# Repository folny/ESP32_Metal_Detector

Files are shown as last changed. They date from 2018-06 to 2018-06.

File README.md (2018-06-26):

# ESP32 Metal Detector

BLE Library https://github.com/nkolban/ESP32_BLE_Arduino

Forum http://www.geotech1.com/forums/showthread.php?24589-ESP32-Metal-detector

https://www.youtube.com/watch?v=ikg0VJCtUzE

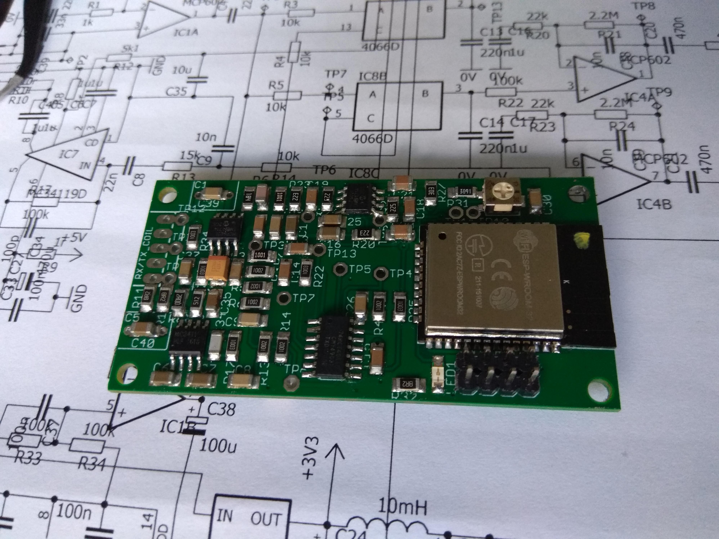
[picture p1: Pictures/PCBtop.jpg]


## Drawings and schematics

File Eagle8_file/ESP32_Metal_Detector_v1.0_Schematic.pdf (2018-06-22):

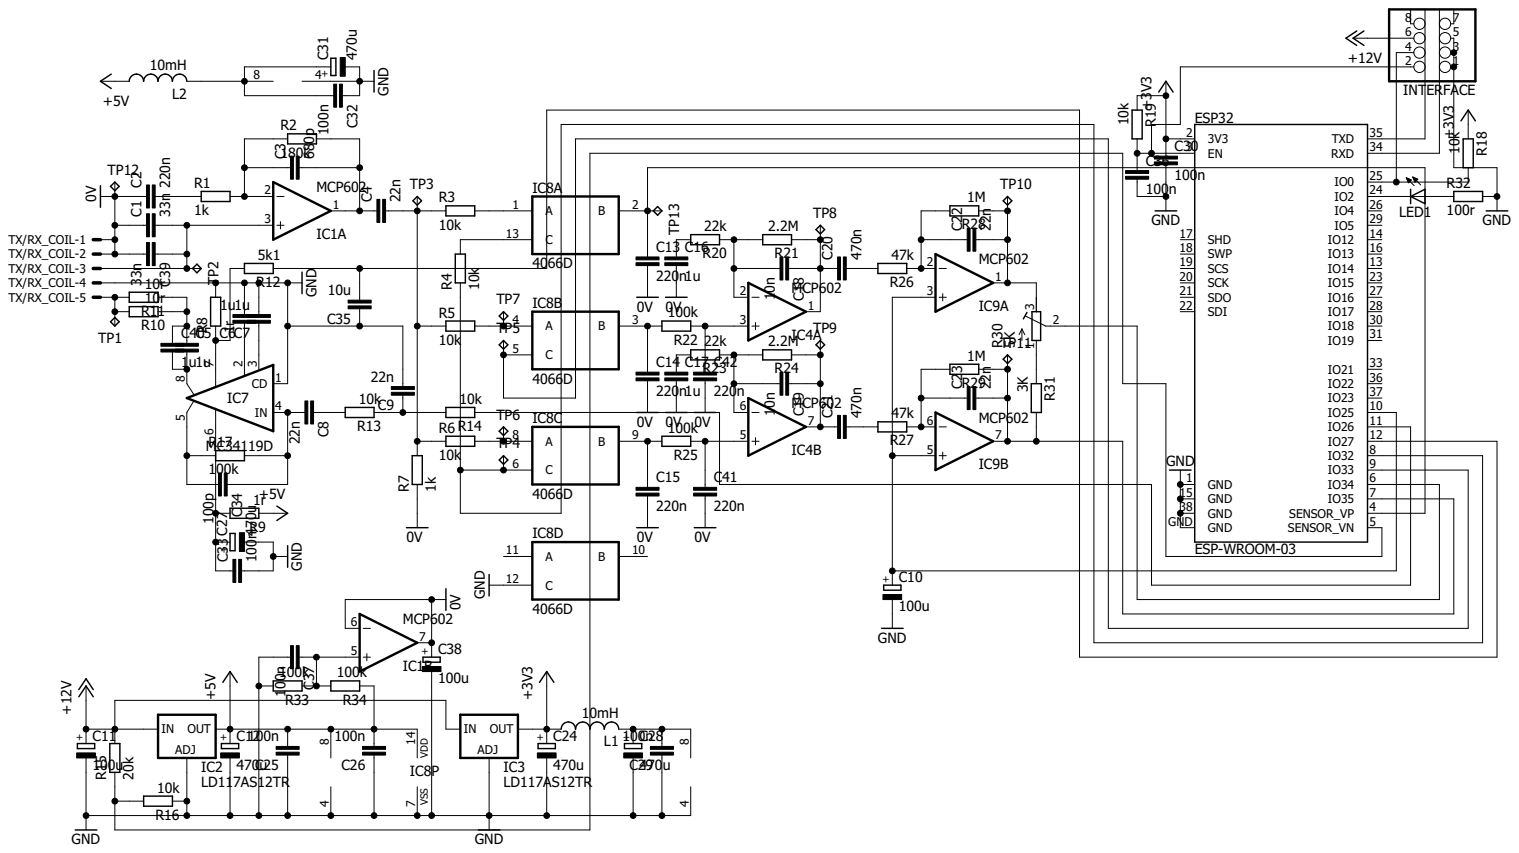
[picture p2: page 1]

TX/RX_COIL-1 TX/RX_COIL-2 TX/RX_COIL-3 TX/RX_COIL-4 TX/RX_COIL-5

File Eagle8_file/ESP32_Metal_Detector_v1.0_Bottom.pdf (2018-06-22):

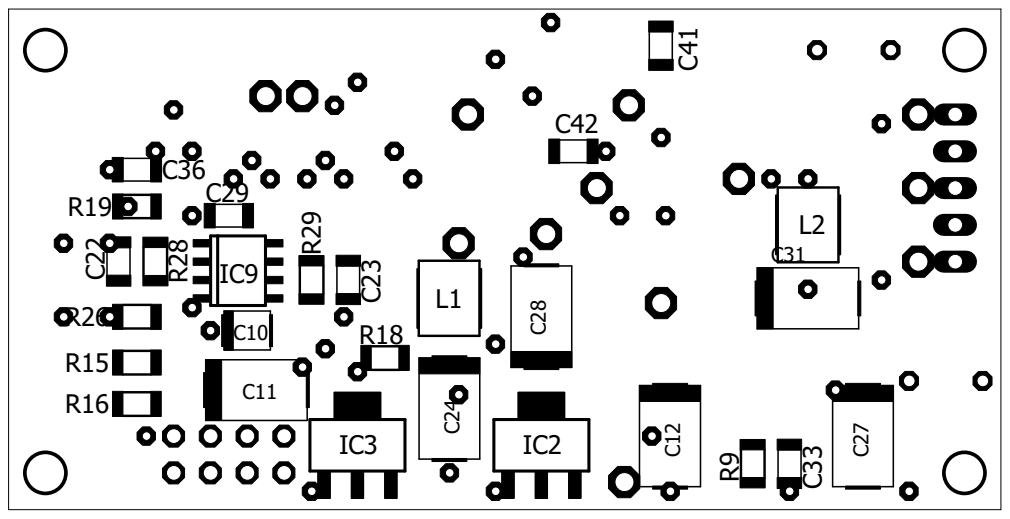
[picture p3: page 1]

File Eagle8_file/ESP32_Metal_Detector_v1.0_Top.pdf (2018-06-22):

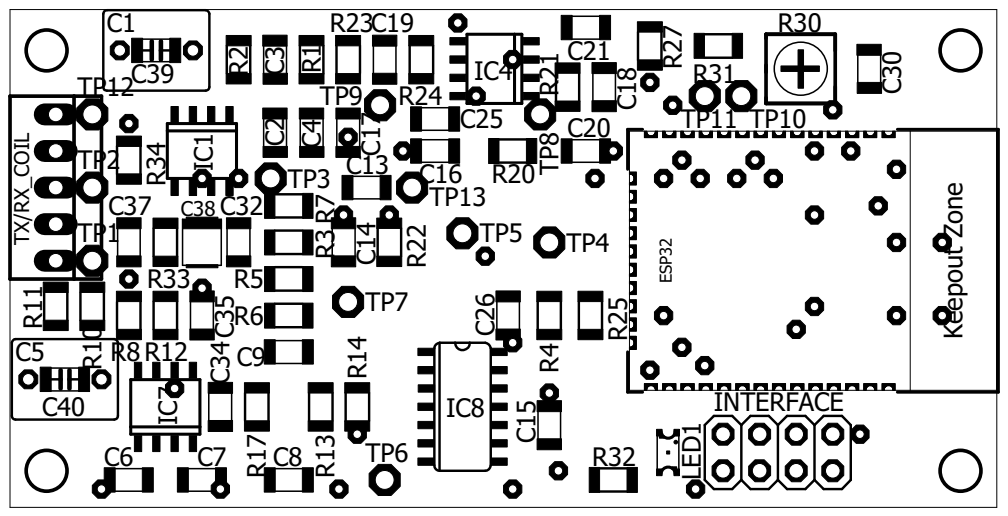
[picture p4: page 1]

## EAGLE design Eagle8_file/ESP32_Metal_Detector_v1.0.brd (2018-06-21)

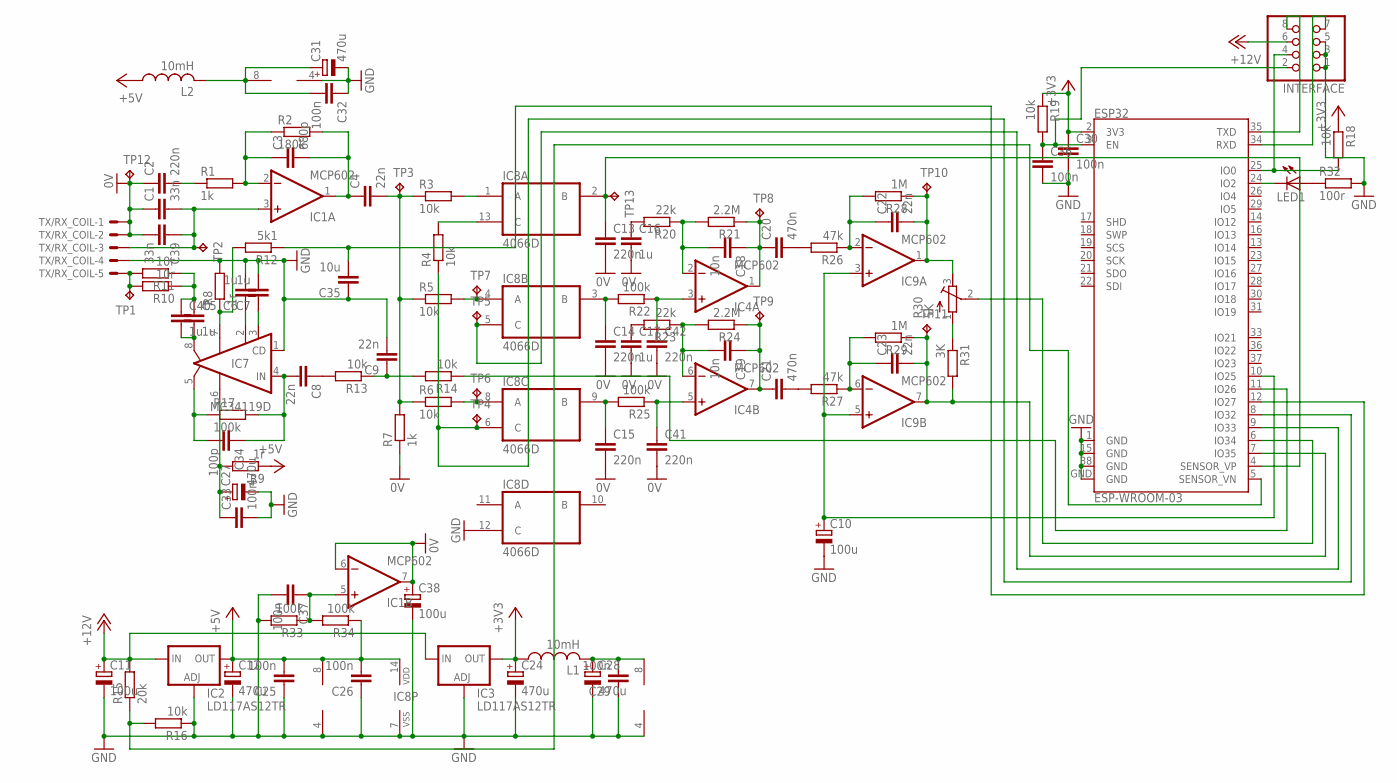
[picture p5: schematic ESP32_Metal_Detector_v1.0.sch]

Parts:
C1: 33n; C050-055X075
C2, C13, C14, C15, C41, C42: 220n; C1206
C3: 680p; C1206
C4, C8, C9, C22, C23: 22n; C1206
C5: 1u; C050-055X075
C6, C7, C16, C17, C40: 1u; C1206
C10, C38: 100u; SMC_B
C11: 100u; SMC_E
C12, C24, C27, C28, C31: 470u; SMC_D
C18, C19: 10n; C1206
C20, C21: 470n; C1206
C25, C26, C29, C30, C32, C33, C36, C37: 100n; C1206
C34: 100p; C1206
C35: 10u; C1206
C39: 33n; C1206
ESP32: ESP-WROOM-03
IC1, IC4, IC9: MCP602; SO08
IC2, IC3: LD117AS12TR; SOT223
IC7: MC34119D; SO08
IC8: 4066D; SO14
INTERFACE: PINHD-2X4; 2X04
L1, L2: 10mH; L5650M
LED1: LEDSML1206; SML1206
R1, R7: 1k; R1206
R2: 180k; R1206
R3, R4, R5, R6, R13, R14, R16, R18, R19: 10k; R1206
R8, R9: 1r; R1206
R10, R11: 10r; R1206
R12: 5k1; R1206
R15: 20k; R1206
R17, R22, R25, R33, R34: 100k; R1206
R20, R23: 22k; R1206
R21, R24: 2.2M; R1206
R26, R27: 47k; R1206
R28, R29: 1M; R1206
R30: 5K; RTRIM4G/J
R31: 3K; R1206
R32: 100r; R1206
TP1, TP2, TP3, TP4, TP5, TP6, TP7, TP8, TP9, TP10, TP11, TP12, TP13: TPPAD1-13; P1-13
TX/RX_COIL: 22-23-2051

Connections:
0V: C1.1, C2.1, C13.2, C14.2, C15.2, C16.2, C17.2, C38.+, C39.2, C41.2, C42.2, IC1.6 (-IN), IC1.7 (OUT), R7.1, TP12.TP, TX/RX_COIL.1, TX/RX_COIL.2
+3V3: C24.+, C30.1, ESP32.2 (3V3), IC3.4 (OUT), L1.1, R18.1, R19.1
+5V: C12.+, C25.2, C26.2, IC2.4 (OUT), IC4.8 (V+), IC8.14 (VDD), L2.1, R9.1, R34.1
+12V: C11.+, IC2.3 (IN), IC3.3 (IN), INTERFACE.6, R15.2
GND: C6.2, C7.2, C9.2, C10.-, C11.-, C12.-, C24.-, C25.1, C26.1, C27.-, C28.-, C29.1, C30.2, C31.-, C32.1, C33.2, C35.1, C36.2, C37.2, C38.-, ESP32.1 (GND), ESP32.15 (GND), ESP32.38 (GND), ESP32.GND, IC1.4 (V-), IC2.1 (ADJ), IC3.1 (ADJ), IC4.4 (V-), IC7.1 (CD), IC8.7 (VSS), IC8.12 (C), IC9.4 (V-), INTERFACE.1, INTERFACE.3, INTERFACE.5, R8.2, R16.1, R32.2, R33.2, TX/RX_COIL.4
unnamed: C3.2, C4.1, IC1.1 (OUT), R2.2
unnamed: R30.1 (A), R31.1
unnamed: C1.2, C39.1, IC1.3 (+IN), TP2.TP, TX/RX_COIL.3
unnamed: C2.2, R1.1
unnamed: C3.1, IC1.2 (-IN), R1.2, R2.1
unnamed: ESP32.8 (IO32), IC8.6 (C), R4.1, TP4.TP
unnamed: IC8.1 (A), R3.2
unnamed: IC8.8 (A), R6.2, TP6.TP
unnamed: C4.2, R3.1, R5.1, R6.1, R7.2, TP3.TP
unnamed: C22.2, IC9.1 (OUT), R28.1, R30.3 (E), TP10.TP
unnamed: IC8.13 (C), R4.2
unnamed: C5.2, C40.2, IC7.8 (VO2)
unnamed: C5.1, C40.1, R10.1, R11.1
unnamed: C15.1, IC8.9 (B), R25.2
unnamed: C27.+, C33.1, IC7.6 (VCC), R9.2
unnamed: IC7.7 (GND), R8.1, R12.2
unnamed: C6.1, IC7.2 (FC2)
unnamed: C7.1, IC7.3 (FC1)
unnamed: C8.2, C34.1, IC7.4 (IN), R17.2
unnamed: C8.1, R13.2
unnamed: C9.1, R13.1, R14.2
unnamed: ESP32.11 (IO26), R14.1
unnamed: C28.+, C29.2, IC9.8 (V+), L1.2
unnamed: IC8.4 (A), R5.2, TP7.TP
unnamed: C14.1, IC8.3 (B), R22.2
unnamed: ESP32.5 (SENSOR_VN), R15.1, R16.2
unnamed: ESP32.9 (IO33), IC8.5 (C), TP5.TP
unnamed: ESP32.6 (IO34), R30.2 (S)
unnamed: C13.1, ESP32.4 (SENSOR_VP), IC8.2 (B), TP13.TP
unnamed: C31.+, C32.2, IC1.8 (V+), L2.2
unnamed: C34.2, IC7.5 (VO1), R17.1
unnamed: C18.1, C20.1, IC4.1 (OUT), R21.1, TP8.TP
unnamed: C18.2, IC4.2 (-IN), R20.1, R21.2
unnamed: C19.2, IC4.6 (-IN), R23.1, R24.2
unnamed: C35.2, ESP32.12 (IO27), R12.1
unnamed: C42.1, IC4.3 (+IN), R22.1
unnamed: C41.1, IC4.5 (+IN), R25.1
unnamed: C20.2, R26.2
unnamed: C21.2, R27.2
unnamed: C23.1, IC9.6 (-IN), R27.1, R29.2
unnamed: C22.1, IC9.2 (-IN), R26.1, R28.2
unnamed: ESP32.25 (IO0), INTERFACE.4, R18.2
unnamed: C23.2, ESP32.7 (IO35), IC9.7 (OUT), R29.1, R31.2, TP11.TP
unnamed: C10.+, ESP32.10 (IO25), IC9.3 (+IN), IC9.5 (+IN)
unnamed: C19.1, C21.1, IC4.7 (OUT), R24.1, TP9.TP
unnamed: LED1.A, R32.1
unnamed: C36.1, ESP32.3 (EN), INTERFACE.2, R19.2
unnamed: C16.1, R20.2
unnamed: C17.1, R23.2
unnamed: R10.2, R11.2, TP1.TP, TX/RX_COIL.5
unnamed: ESP32.24 (IO2), LED1.C
unnamed: C37.1, IC1.5 (+IN), R33.1, R34.2
unnamed: ESP32.35 (TXD), INTERFACE.8
unnamed: ESP32.34 (RXD), INTERFACE.7

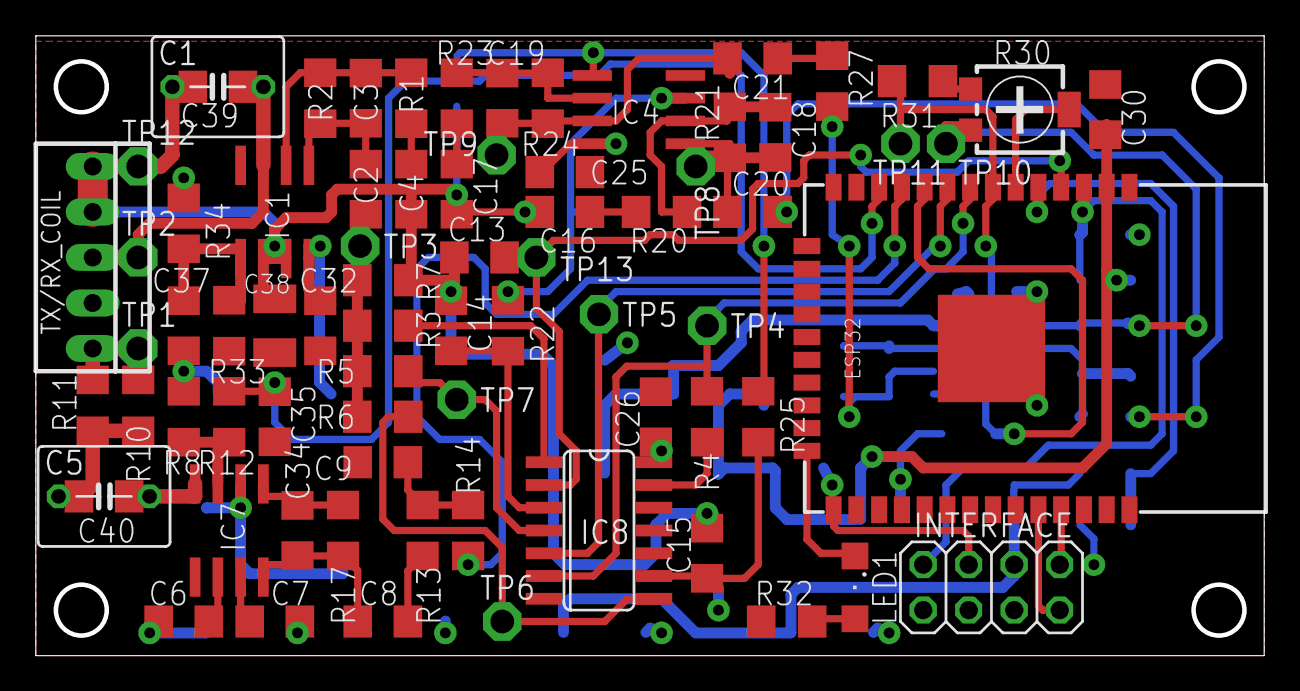
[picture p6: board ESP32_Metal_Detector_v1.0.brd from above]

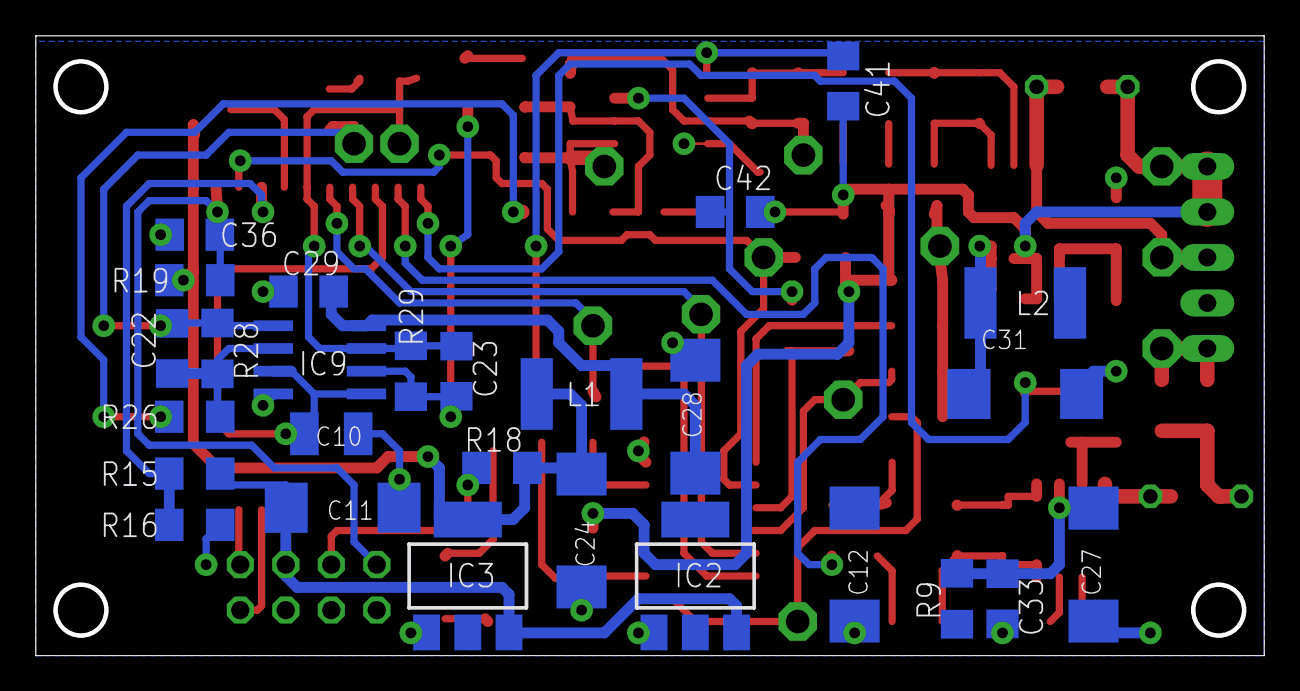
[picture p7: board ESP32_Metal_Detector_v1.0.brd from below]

Board: 2 copper layers, 68.6 x 34.6 mm, 102 parts (27 on the bottom side), 59 nets.

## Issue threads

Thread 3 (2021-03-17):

setup process step by step

DVB-Arduino, 2021-03-17:
I made this project. But I can't configure it. The firmware is uploaded to ESP32, the phone sees the bluetooth of the metal detector and connects ..
But I ran into a problem:
1. APK application does not work on Android 10. Writes that the program was created for an early version of Android.
2. No generation on IO26 ESP32. (transmitting signal)

Can you describe the setup process step by step?

renat2985, 2021-04-06:
Can you show how you connected the board to the coil?

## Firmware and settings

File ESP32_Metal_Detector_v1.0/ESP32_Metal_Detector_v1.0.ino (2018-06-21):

#include <WiFi.h>
#include <ESPmDNS.h>
#include <WiFiUdp.h>
#include <ArduinoOTA.h>
#include <EEPROM.h>
#include <Arduino.h>
#include <driver/dac.h>
#include <BLEDevice.h>
#include <BLEServer.h>
#include <BLEUtils.h>
#include <BLE2902.h>

#include "defs.h"
#include "params.h"
#include "config.h"

bool InfoSend = 0;
bool ledStatus = 0;
bool CalibZeroSelected = 0;
bool CalibMaxSelected = 0;

CParameters params;
extern CParameters params;

const char* ssid = "ESP32 Metal Detector";
const char* password = "detectorupdate";

int VDI = 0;
int MSG = 0;

char DataString[16];

BLECharacteristic *pCharacteristic_RX;
BLECharacteristic *pCharacteristic_TX;

bool deviceConnected = false;

#define SERVICE_UUID                 "6E400001-B5A3-F393-E0A9-E50E24DCCA9E"
#define CHARACTERISTIC_UUID_RX       "6E400002-B5A3-F393-E0A9-E50E24DCCA9E"
#define CHARACTERISTIC_UUID_TX       "6E400003-B5A3-F393-E0A9-E50E24DCCA9E"

class MyServerCallbacks: public BLEServerCallbacks {
    void onConnect(BLEServer* pServer) {
      deviceConnected = true;
      ledStatus = 0;
      InfoSend = 1;
      digitalWrite(2, HIGH);
      Serial.println("Bluetooth Connected");
    };

void onDisconnect(BLEServer* pServer) {
      deviceConnected = false;
      ledStatus = 1;
      Serial.println("Bluetooth Disonnected");
      //ESP.restart();
    }
};

class MyCallbacks: public BLECharacteristicCallbacks {
    void onWrite(BLECharacteristic *pCharacteristic) {
      std::string rxValue = pCharacteristic->getValue();

//////////////////////////////////////////////////////////////////

if (rxValue.find("B") != -1)
        { 
     if (params.m_minSignal <255)
        {
         params.m_minSignal ++;//if pin0 is pressed and the duty ratio value is less than 255
         delay(50);                                               
        }
        }
     if (rxValue.find("A") != -1)
        {
     if (params.m_minSignal >0)
        {
         params.m_minSignal --;// if pin1 is pressed and the duty ratio value is greater than 0
         delay(50);                                              
        }                                                
}
        
//////////////////////////////////////////////////////////////////

if (rxValue.find("D") != -1)
        { 
     if (params.m_readingSamples <255)
        {
         params.m_readingSamples ++;//if pin0 is pressed and the duty ratio value is less than 255
         delay(50);                                               
        }
        }
     if (rxValue.find("C") != -1)
        {
     if (params.m_readingSamples >0)
        {
         params.m_readingSamples --;// if pin1 is pressed and the duty ratio value is greater than 0
         delay(50);                                              
        }                                                
}
         
//////////////////////////////////////////////////////////////////

if (rxValue.find("F") != -1)
        { 
     if (params.m_Phase_X <255)
        {
         params.m_Phase_X ++;//if pin0 is pressed and the duty ratio value is less than 255
         delay(50);                                               
        }
        }
     if (rxValue.find("E") != -1)
        {
     if (params.m_Phase_X >0)
        {
         params.m_Phase_X --;// if pin1 is pressed and the duty ratio value is greater than 0
         delay(50);                                              
        }                                                
}
         
//////////////////////////////////////////////////////////////////

         if (rxValue.find("I") != -1) {
         CalibZeroSelected = 1;      
       }
       
         if (rxValue.find("J") != -1) {
         CalibMaxSelected = 1;
       }
             
         EEPROMWriteInt(2, params.m_minSignal);
         EEPROMWriteInt(10, params.m_readingSamples);
         EEPROMWriteInt(14, params.m_Phase_X);
         Serial.print("MinSignal EEPROM Write :"); 
         Serial.println(params.m_minSignal);
         Serial.print("ReadingSamples EEPROM Write :"); 
         Serial.println(params.m_readingSamples);
         Serial.print("Phase_X EEPROM Write :"); 
         Serial.println(params.m_Phase_X);
    }
};

///////////////////////////////////////////////////////////////////////////////////////////////////////
//signal processing
bool generateReading(int* pPhase, int* pStrength, unsigned char* signalValues, bool* pbadReading) 
{
    #define SAMPLE_BUFFER_SIZE 350
    unsigned char strenth[SAMPLE_BUFFER_SIZE] = {0,};
    unsigned char angle[SAMPLE_BUFFER_SIZE] = {0,};
    int index = 0;

    bool enoughSamples = false;
    unsigned long startTime = millis();
    bool needToClearLastResult = true;
    bool retValue = true;

    while(1)
   {
     if (ledStatus == 1) {
     LED();
   }   
     if (InfoSend == 1) {
     delay(2000);
     sprintf(DataString, "%d,%d,%d,%d,%d,%d",-99,200, params.m_minSignal, params.m_readingSamples, params.m_Phase_X, params.m_Battery);    
     pCharacteristic_TX->setValue(DataString); 
     pCharacteristic_TX->notify();
     Serial.println(DataString);
     InfoSend = 0;
  }   
    //ArduinoOTA.handle();
    if (CalibZeroSelected == 1) {
    onCalibZeroSelected();   
    CalibZeroSelected = 0;
  }
 
    if (CalibMaxSelected == 1) {
    onCalibMaxSelected(); 
    CalibMaxSelected = 0;
  } 
      //sample signals
      float X = 0.0F;
      float R = 0.0F;
      const int SAMPLING_LOOP = params.m_readingSamples;
      for(int n(0);n<SAMPLING_LOOP;n++)
      {
        X += analogRead(Rx_XPin);
        R += analogRead(Rx_RPin);
      }
      X /= SAMPLING_LOOP;
      R /= SAMPLING_LOOP;

      //if opamp is saturated; break and report it
      if(X >= params.m_maxSignal || R >= params.m_maxSignal)
      {
        *pbadReading = true;
        Serial.println("Sinal MAX !");

        MSG = 201;
        sprintf(DataString, "%d,%d,%d,%d,%d,%d",VDI, MSG, params.m_minSignal, params.m_readingSamples, params.m_Phase_X, params.m_Battery);        
        pCharacteristic_TX->setValue(DataString); 
        pCharacteristic_TX->notify();
        break;
      }
      
      //bring to "virtual ADC zero"
      X = X - params.m_XBias;
      R = R - params.m_RBias;  

      //screen out samples using signal R polarity as set in params
      // 0 - use any polarity
      //-1 - use only negative R
      // 1 - use only positive R
      if( (params.m_sigPolarity<0 && R>0) || (params.m_sigPolarity>0 && R<0) )
      {
        X = 0.0F;
        R = 0.0F;
      }

      //phase in degrees
      int phase = ( (X == 0.0F && R == 0.0F) ? 0 : atan2(X, R) * 57.295F ); 
      if(phase < -90)
       phase = -90;
      else if(phase > 90) 
       phase = 90;
        
      angle[index]   = phase + 90;
      strenth[index] = int(sqrt(X*X+R*R));
      index++;

      //ring buffer; wrap around
      if(index >= SAMPLE_BUFFER_SIZE)
      {
        enoughSamples = true; 
        index = 0;
      }

      if(!enoughSamples)
        continue;

      //find peak signal
      unsigned char maxVal = 0;
      int maxIndex = -1;
      for(int n(0); n<SAMPLE_BUFFER_SIZE; n++)
      {
        if(strenth[n] > maxVal)
        {
          maxVal = strenth[n];
          maxIndex = n;               
        }
      }

      //is the peak strong enough
      if(maxVal < params.m_minSignal)
      {
        //no strong signal is present; its a good time to clear LCD if needed
        if(needToClearLastResult && (millis() - startTime) > 4000)
        {
          unsigned char empty[40]={0};    
          needToClearLastResult = false;

         VDI = -99;
         MSG = 200;
         sprintf(DataString, "%d,%d,%d,%d,%d,%d",VDI, MSG, params.m_minSignal, params.m_readingSamples, params.m_Phase_X, params.m_Battery);       
         pCharacteristic_TX->setValue(DataString); 
         pCharacteristic_TX->notify();
        }
        continue;
      }

      //where in the buffer is the peak
      int dist = index - maxIndex;
      if(dist < 0)
        dist = SAMPLE_BUFFER_SIZE + dist;

      //check if the peak is in the middle of the buffer
      if(dist != SAMPLE_BUFFER_SIZE/2)
        continue; 

      //////////////////////////////////////////////////////////////////////////////////////////////////////////
      //we have strong enough peak in the middle of sampling buffer
      //calculate the result and break the loop
      float angleAvg = 0.0F;
      float strengthAvg = 0.0F;
      int avgSamples = 0;
      const int reach = 1;        
      int n = maxIndex - reach;
      while(avgSamples < (reach*2 + 1))
      {
        if(n<0)
          n += SAMPLE_BUFFER_SIZE;
        else if(n>=SAMPLE_BUFFER_SIZE) 
          n %= SAMPLE_BUFFER_SIZE;  
            
        angleAvg    += (int(angle[n]) - 90);
        strengthAvg += strenth[n];  
        avgSamples++;
        n++;
      }

      *pPhase = angleAvg/avgSamples;
      *pStrength = strengthAvg/avgSamples; 
      
      if (deviceConnected) {
      int VDI = angleAvg/avgSamples; // This could be an actual sensor reading!

      MSG = 0;
      sprintf(DataString, "%d,%d,%d,%d,%d,%d",VDI, MSG, params.m_minSignal, params.m_readingSamples, params.m_Phase_X, params.m_Battery);        
      pCharacteristic_TX->setValue(DataString); 
      pCharacteristic_TX->notify();
      }
      
       Serial.println(*pPhase);

      //prepare data for the 40x8 graph      
      int k = index;
      const int inc = SAMPLE_BUFFER_SIZE/40;  
      int32_t i = 0;      
      while(i<40){
        if(index>=SAMPLE_BUFFER_SIZE) 
           index -= SAMPLE_BUFFER_SIZE;  
        
        signalValues[i] = float(strenth[index])/float(maxVal) * 8;

        index+=inc;
        i++;
      }
      //measurement completed; break the loop
       break;
    }
  return retValue;
}

////////////////////////////////////////////////////////////////////////////////////
// Standard arduino functions
void setup()
{
  Serial.begin(115200);

  //WiFi.mode(WIFI_AP);
  //WiFi.softAP(ssid, password);
  //WiFi.softAPConfig(IPAddress (192,168,1,1),IPAddress (192,168,1,1),IPAddress (255,255,255,0));
  //WiFi.setHostname("ESP32_Metal_Detector");

  //ArduinoOTA.setHostname("ESP32_Metal_Detector");  
  //ArduinoOTA.begin();

 // Create the BLE Device
  BLEDevice::init("ESP32 Metal Detector");

  // Create the BLE Server
  BLEServer *pServer = BLEDevice::createServer();
  pServer->setCallbacks(new MyServerCallbacks());


  BLEService *pService = pServer->createService(SERVICE_UUID);
  

  BLECharacteristic *pCharacteristic_RX = pService->createCharacteristic(
                                         CHARACTERISTIC_UUID_RX,
                                         BLECharacteristic::PROPERTY_WRITE
                                       );                  
 
  pCharacteristic_RX->setCallbacks(new MyCallbacks());


  pCharacteristic_TX = pService->createCharacteristic(
                      CHARACTERISTIC_UUID_TX,
                      BLECharacteristic::PROPERTY_READ   |
                      BLECharacteristic::PROPERTY_WRITE  |
                      BLECharacteristic::PROPERTY_INDICATE|
                      BLECharacteristic::PROPERTY_NOTIFY 
                    );
 
  pCharacteristic_TX->addDescriptor(new BLE2902());

  pService->start();
  pServer->getAdvertising()->start();

  analogSetWidth(10); 
  //analogSetCycles(8);
  analogSetAttenuation(ADC_11db);
  //analogSetClockDiv(16);
  //analogSetSamples(16);

 /*
  analogReadResolution(12);             // Sets the sample bits and read resolution, default is 12-bit (0 - 4095), range is 9 - 12 bits
  analogSetWidth(12);                   // Sets the sample bits and read resolution, default is 12-bit (0 - 4095), range is 9 - 12 bits
                                        //  9-bit gives an ADC range of 0-511
                                        // 10-bit gives an ADC range of 0-1023
                                        // 11-bit gives an ADC range of 0-2047
                                        // 12-bit gives an ADC range of 0-4095
  analogSetCycles(8);                   // Set number of cycles per sample, default is 8 and provides an optimal result, range is 1 - 255
  analogSetSamples(1);                  // Set number of samples in the range, default is 1, it has an effect on sensitivity has been multiplied
  analogSetClockDiv(1);                 // Set the divider for the ADC clock, default is 1, range is 1 - 255
  analogSetAttenuation(ADC_11db);       // Sets the input attenuation for ALL ADC inputs, default is ADC_11db, range is ADC_0db, ADC_2_5db, ADC_6db, ADC_11db
  analogSetPinAttenuation(VP,ADC_11db); // Sets the input attenuation, default is ADC_11db, range is ADC_0db, ADC_2_5db, ADC_6db, ADC_11db
                                        // ADC_0db provides no attenuation so IN/OUT = 1 / 1 an input of 3 volts remains at 3 volts before ADC measurement
                                        // ADC_2_5db provides an attenuation so that IN/OUT = 1 / 1.34 an input of 3 volts is reduced to 2.238 volts before ADC measurement
                                        // ADC_6db provides an attenuation so that IN/OUT = 1 / 2 an input of 3 volts is reduced to 1.500 volts before ADC measurement
                                        // ADC_11db provides an attenuation so that IN/OUT = 1 / 3.6 an input of 3 volts is reduced to 0.833 volts before ADC measurement
  adcAttachPin(VP);                     // Attach a pin to ADC (also clears any other analog mode that could be on), returns TRUE/FALSE result 
  adcStart(VP);                         // Starts an ADC conversion on attached pin's bus
  adcBusy(VP);                          // Check if conversion on the pin's ADC bus is currently running, returns TRUE/FALSE result 
  adcEnd(VP);                           // Get the result of the conversion (will wait if it have not finished), returns 16-bit integer result
  */

  pinMode(Rx_XPin, INPUT);
  pinMode(Rx_RPin, INPUT);
  pinMode(Tx_CoilPin, OUTPUT);
  pinMode(LedPin, OUTPUT);
  pinMode(VrefPin, OUTPUT);
  pinMode(BatPin, INPUT);
  pinMode(Phase_X_Pin, OUTPUT);
  pinMode(Phase_R_Pin, OUTPUT);
  digitalWrite(LedPin, LOW);
  
  EEPROM.begin(512);
  
  params.loadParams();
  //params.setDefaults();

  Battery();

  dacWrite(VrefPin, 127); 
   
  ledcAttachPin(Tx_CoilPin, 2);
  ledcSetup(2, params.m_CoilFrequency, 8); 
  ledcWriteTone(2, params.m_CoilFrequency); 
  delayMicroseconds(params.m_Phase_X);  
   
  ledcAttachPin(Phase_X_Pin, 4);
  ledcSetup(4, params.m_CoilFrequency, 8);
  ledcWriteTone(4, params.m_CoilFrequency);
  //ledcWrite(4, 100);
   
  delayMicroseconds(params.m_Phase_R);
  ledcAttachPin(Phase_R_Pin, 6);
  ledcSetup(6, params.m_CoilFrequency, 8);
  ledcWriteTone(6, params.m_CoilFrequency);
  
  Serial.println();
  Serial.println("Boot Finish Print Info");
  Serial.println();

  Serial.print("Hardware Version ");
  Serial.println(HARDWARE_VERSION);

  Serial.print("Firmware Version ");
  Serial.println(FIRMWARE_VERSION);

  Serial.print("WiFi SSID: ");
  Serial.println(ssid);

  Serial.print("WiFi Password: ");
  Serial.println(password);

  Serial.print("IP address: ");
  Serial.println(WiFi.softAPIP());

  Serial.print("Battery: ");
  Serial.print(params.m_Battery);
  Serial.println("V");

  Serial.print("XBias ");
  Serial.println(params.m_XBias);

  Serial.print("RBias ");
  Serial.println(params.m_RBias); 

  Serial.print("minSignal ");
  Serial.println(params.m_minSignal);

  Serial.print("maxSignal ");
  Serial.println(params.m_maxSignal);

  Serial.print("readingSamples ");
  Serial.println(params.m_readingSamples);

  Serial.print("sigPolarity ");
  Serial.println(params.m_sigPolarity);

  Serial.print("Coil Frequency ");
  Serial.print(params.m_CoilFrequency);
  Serial.println(" Hz");

  Serial.print("Phase X ");
  Serial.println(params.m_Phase_X);

  Serial.print("Phase R ");
  Serial.println(params.m_Phase_R);

  ledStatus = 1;   
}

void loop()
{   
    int phase(0.0F);
    int strength(0);
    unsigned char signalValues[40]={0};    
    bool badReading(false);
    if(generateReading(&phase, &strength, signalValues, &badReading))
    {
      
    }
}

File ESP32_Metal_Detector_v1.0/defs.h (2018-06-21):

#ifndef MD_DEFS_H
#define MD_DEFS_H

#define HARDWARE_VERSION "v1.0"
#define FIRMWARE_VERSION "v1.0.0"

#define Rx_XPin 34 
#define Rx_RPin 35
#define Tx_CoilPin 26
#define Phase_X_Pin  32 
#define Phase_R_Pin  33
#define LedPin 2
#define VrefPin 25
#define BatPin 39

#endif
